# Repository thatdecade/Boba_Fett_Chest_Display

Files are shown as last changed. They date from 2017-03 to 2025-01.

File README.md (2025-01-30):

# Boba-Fett-Chest-Display
This is the software and hardware design for the display on Boba Fett’s chest plate.  It was developed in collaboration with Joshua Kane.

The animation script is laid out in an easy to understand format.  Each segment of the display is fully programmable in the animation.
Just 12 lines of code to processes the animation and update the display!

Video Demo: https://www.flickr.com/photos/dwest2/23788341410

Video Build Guide: https://youtu.be/qv9qykpNFjM

Part List: https://www.mouser.com/ProjectManager/ProjectDetail.aspx?AccessID=554d07ab05

PCB Main Board: https://oshpark.com/shared_projects/f60TBgnX

PCB Bargraph Board: https://www.oshpark.com/shared_projects/E4qjCF4r

PCB Assembly Guide: http://www.westaby.net/2016/01/guide-boba-fett-chest-display/

Animation sequences for ESB, RTOJ, and Mandalorian are included.  For a customized sequence:
- Open the sequence_builder.xlsx or visit: https://www.westaby.net/7seg/
- There are three tabs, Seq Builder, Encoder, and Decoder.
- On the Seq Builder tab, enter 1s and 0s to light up the characters as you wish.
- Copy the indicated cell and paste the values to the sequence rows (right click, paste values)
- When finished, copy the finished sequence into the arduino code.
- Update CHAR_SEQUENCE_SIZE with the number of lines in your animation sequence
------------------------
# Boba-Fett-Chest-Display

This is the software and hardware design for the display on Boba Fett’s chest plate. It was developed in collaboration with Joshua Kane.

The animation script is laid out in an easy to understand format.  Each segment of the display is fully programmable in the animation.
Just 12 lines of code to processes the animation and update the display!

## Video Resources
- **Video Demo**: [Watch on Flickr](https://www.flickr.com/photos/dwest2/23788341410)
- **Video Build Guide**: [Watch on YouTube](https://youtu.be/qv9qykpNFjM)

## Hardware Resources
- **Part List**: [View on Mouser](https://www.mouser.com/ProjectManager/ProjectDetail.aspx?AccessID=554d07ab05)
- **PCB Main Board**: [View on OshPark](https://oshpark.com/shared_projects/f60TBgnX)
- **PCB Bargraph Board**: [View on OshPark](https://www.oshpark.com/shared_projects/E4qjCF4r)
- **PCB Assembly Guide**: [Read the Guide](http://www.westaby.net/2016/01/guide-boba-fett-chest-display/)

## Animation Sequences
Animation sequences for **ESB**, **ROTJ**, and **Mandalorian** are included. To create a customized sequence, follow these steps using the [7-Segment LED Display Animator Tool](https://www.westaby.net/7seg/):

1. **Open the Animator Tool**: [https://www.westaby.net/7seg/](https://www.westaby.net/7seg/) 

2. **Create Your Animation**:
   - Click on the segments of each digit to turn them on or off, creating your desired pattern.
   - Click the **"Save Frame"** button to record the current state of the display, adding it as a frame in your animation sequence.
   - Click the **"Playback Animation"** button to preview your animation on the display.
   - Once satisfied with your animation, click the **"Copy Code"** button to copy the animation data to your clipboard. This can be directly pasted into your Arduino code.

3. **Configure Arduino Code**:
   - In your Arduino sketch, paste the copied animation data where appropriate.
   - Update the `CHAR_SEQUENCE_SIZE` constant to match the number of frames in your animation sequence.

## Getting Started
1. **Assemble the Hardware**:
   - Follow the [PCB Assembly Guide](http://www.westaby.net/2016/01/guide-boba-fett-chest-display/) to assemble the main and bargraph PCBs.
   - Ensure all components are correctly placed and soldered.

2. **Upload the Firmware**:
   - Connect your assembled display to your computer via USB.
   - Open the Arduino IDE and load your sketch.  
   - Paste the animation data into your sketch and upload it to the microcontroller.

3. **Power Up**:
   - Once the firmware is uploaded, power the display to see your custom animations in action.

## License
[GNU General Public License v3.0](LICENSE)

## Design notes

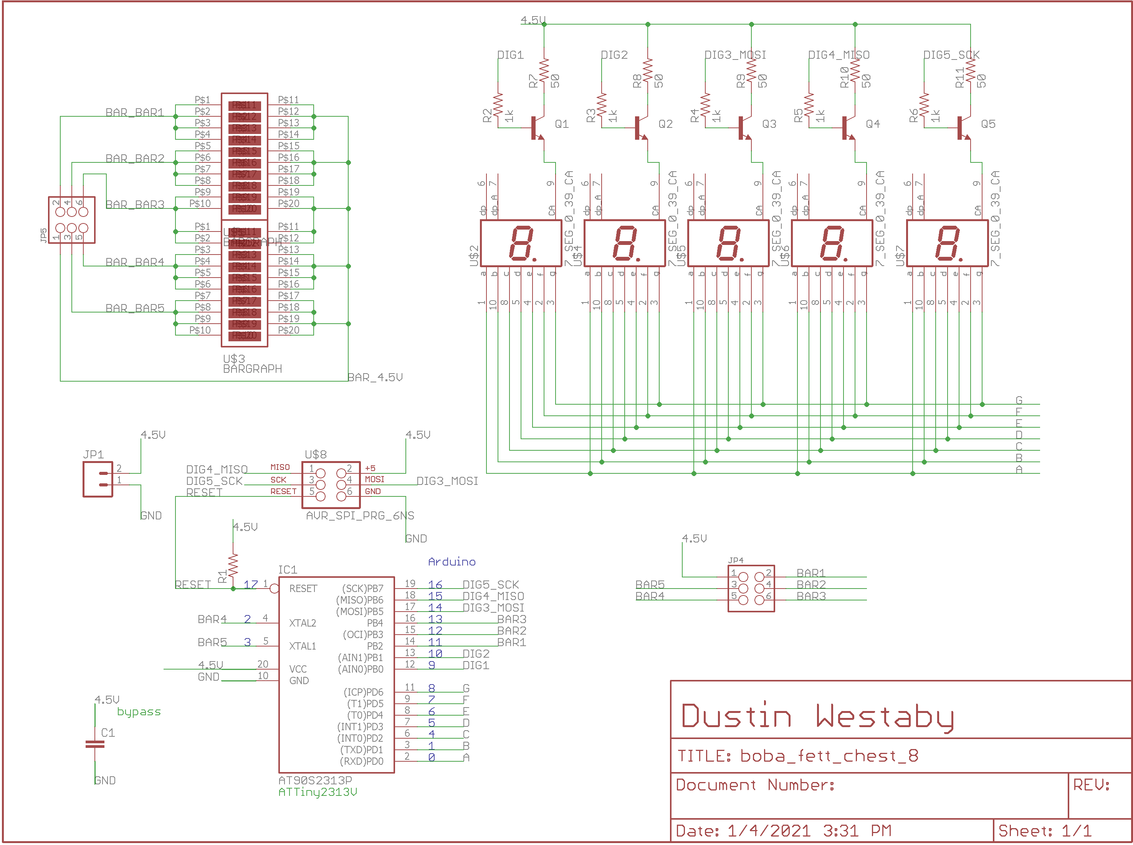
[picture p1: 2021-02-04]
PCB/schematic.png

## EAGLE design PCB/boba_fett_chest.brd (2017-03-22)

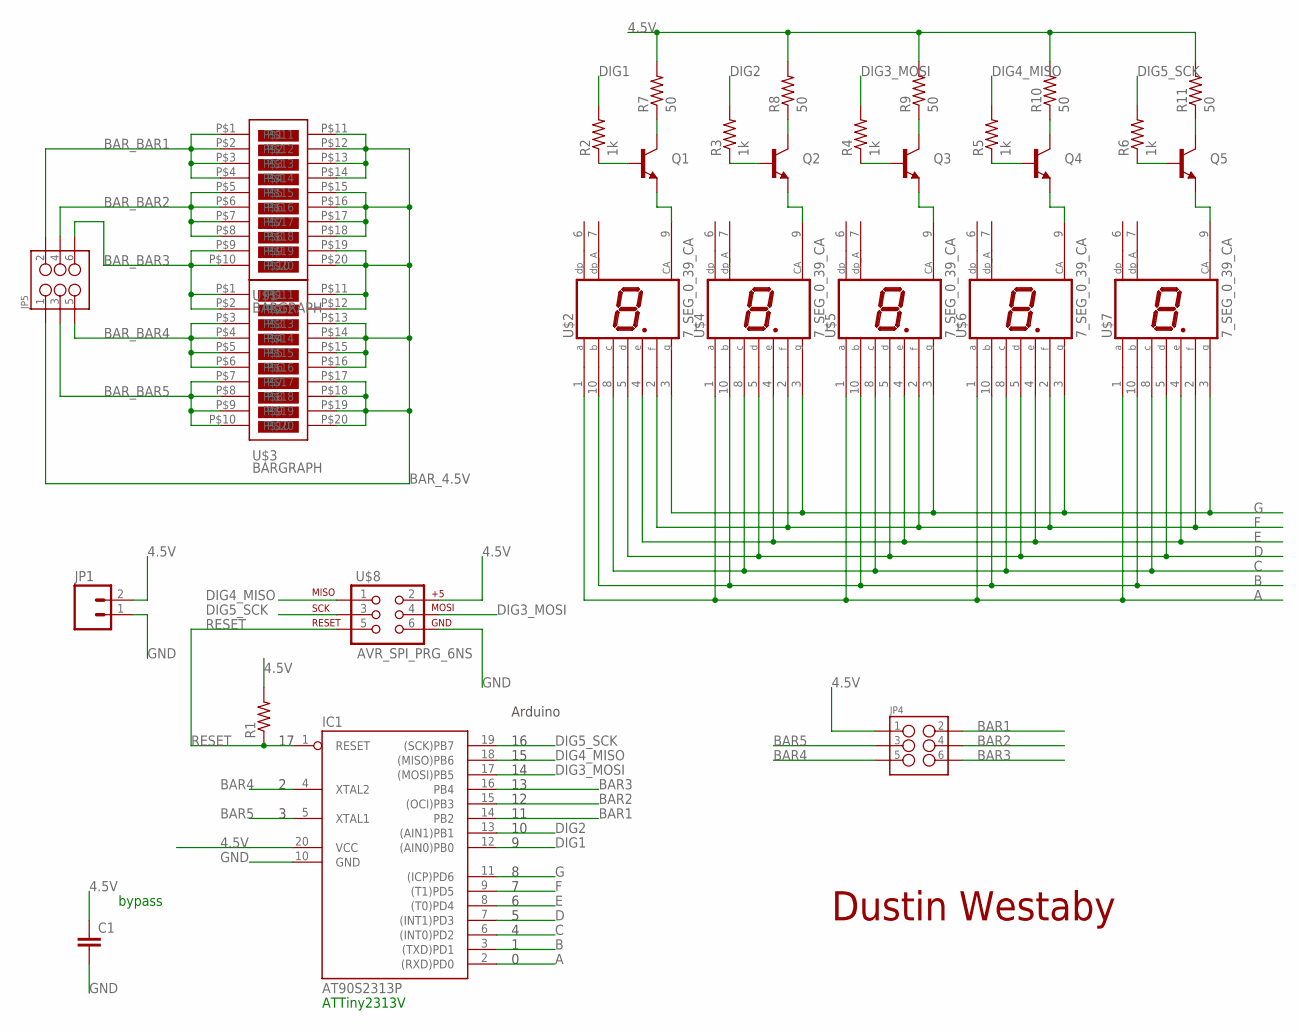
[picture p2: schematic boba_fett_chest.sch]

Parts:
C1: CAPCAP-PTH-2MM; CAP-PTH-2MM
IC1: AT90S2313P; DIL20
JP1: M02PTH; 1X02
JP4, JP5: M03X22X3_SILK_SM; 2X3
Q1, Q2, Q3, Q4, Q5: TRANSISTOR_NPNTO92; TO-92
R1: RESISTORPTH1; AXIAL-0.3
R2, R3, R4, R5, R6: 1k; AXIAL-0.3
R7, R8, R9, R10, R11: 50; AXIAL-0.3
U$1, U$3: BARGRAPH
U$2, U$4, U$5, U$6, U$7: 7_SEG_0_39_CA; 0_39_DISP
U$8: AVR_SPI_PRG_6NS; 2X3-NS

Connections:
4.5V: C1.1, IC1.20 (VCC), JP1.2, JP4.1, R1.P$2 (2), R7.P$2 (2), R8.P$2 (2), R9.P$2 (2), R10.P$2 (2), R11.P$2 (2), U$8.2
A: IC1.2 ((RXD)PD0), U$2.1 (A), U$4.1 (A), U$5.1 (A), U$6.1 (A), U$7.1 (A)
B: IC1.3 ((TXD)PD1), U$2.10 (B), U$4.10 (B), U$5.10 (B), U$6.10 (B), U$7.10 (B)
BAR1: IC1.14 (PB2), JP4.2
BAR2: IC1.15 ((OCI)PB3), JP4.4
BAR3: IC1.16 (PB4), JP4.6
BAR4: IC1.4 (XTAL2), JP4.5
BAR5: IC1.5 (XTAL1), JP4.3
BAR_4.5V: JP5.1, U$1.P$11, U$1.P$12, U$1.P$13, U$1.P$14, U$1.P$15, U$1.P$16, U$1.P$17, U$1.P$18, U$1.P$19, U$1.P$20, U$3.P$11, U$3.P$12, U$3.P$13, U$3.P$14, U$3.P$15, U$3.P$16, U$3.P$17, U$3.P$18, U$3.P$19, U$3.P$20
BAR_BAR1: JP5.2, U$1.P$1, U$1.P$2, U$1.P$3, U$1.P$4
BAR_BAR2: JP5.4, U$1.P$5, U$1.P$6, U$1.P$7, U$1.P$8
BAR_BAR3: JP5.6, U$1.P$9, U$1.P$10, U$3.P$1, U$3.P$2
BAR_BAR4: JP5.5, U$3.P$3, U$3.P$4, U$3.P$5, U$3.P$6
BAR_BAR5: JP5.3, U$3.P$7, U$3.P$8, U$3.P$9, U$3.P$10
C: IC1.6 ((INT0)PD2), U$2.8 (C), U$4.8 (C), U$5.8 (C), U$6.8 (C), U$7.8 (C)
D: IC1.7 ((INT1)PD3), U$2.5 (D), U$4.5 (D), U$5.5 (D), U$6.5 (D), U$7.5 (D)
DIG1: IC1.12 ((AIN0)PB0), R2.P$2 (2)
DIG2: IC1.13 ((AIN1)PB1), R3.P$2 (2)
DIG3_MOSI: IC1.17 ((MOSI)PB5), R4.P$2 (2), U$8.4
DIG4_MISO: IC1.18 ((MISO)PB6), R5.P$2 (2), U$8.1
DIG5_SCK: IC1.19 ((SCK)PB7), R6.P$2 (2), U$8.3
E: IC1.8 ((T0)PD4), U$2.4 (E), U$4.4 (E), U$5.4 (E), U$6.4 (E), U$7.4 (E)
F: IC1.9 ((T1)PD5), U$2.2 (F), U$4.2 (F), U$5.2 (F), U$6.2 (F), U$7.2 (F)
G: IC1.11 ((ICP)PD6), U$2.3 (G), U$4.3 (G), U$5.3 (G), U$6.3 (G), U$7.3 (G)
GND: C1.2, IC1.10 (GND), JP1.1, U$8.6
unnamed: Q5.1 (E), U$7.9 (CA)
unnamed: Q4.1 (E), U$6.9 (CA)
unnamed: Q3.1 (E), U$5.9 (CA)
unnamed: Q2.1 (E), U$4.9 (CA)
unnamed: Q1.1 (E), U$2.9 (CA)
unnamed: Q1.2 (B), R2.P$1 (1)
unnamed: Q2.2 (B), R3.P$1 (1)
unnamed: Q3.2 (B), R4.P$1 (1)
unnamed: Q4.2 (B), R5.P$1 (1)
unnamed: Q5.2 (B), R6.P$1 (1)
unnamed: Q1.3 (C), R7.P$1 (1)
unnamed: Q2.3 (C), R8.P$1 (1)
unnamed: Q3.3 (C), R9.P$1 (1)
unnamed: Q4.3 (C), R10.P$1 (1)
unnamed: Q5.3 (C), R11.P$1 (1)
RESET: IC1.1 (RESET), R1.P$1 (1), U$8.5

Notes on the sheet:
bypass
ATTiny2313V
Arduino
Dustin Westaby

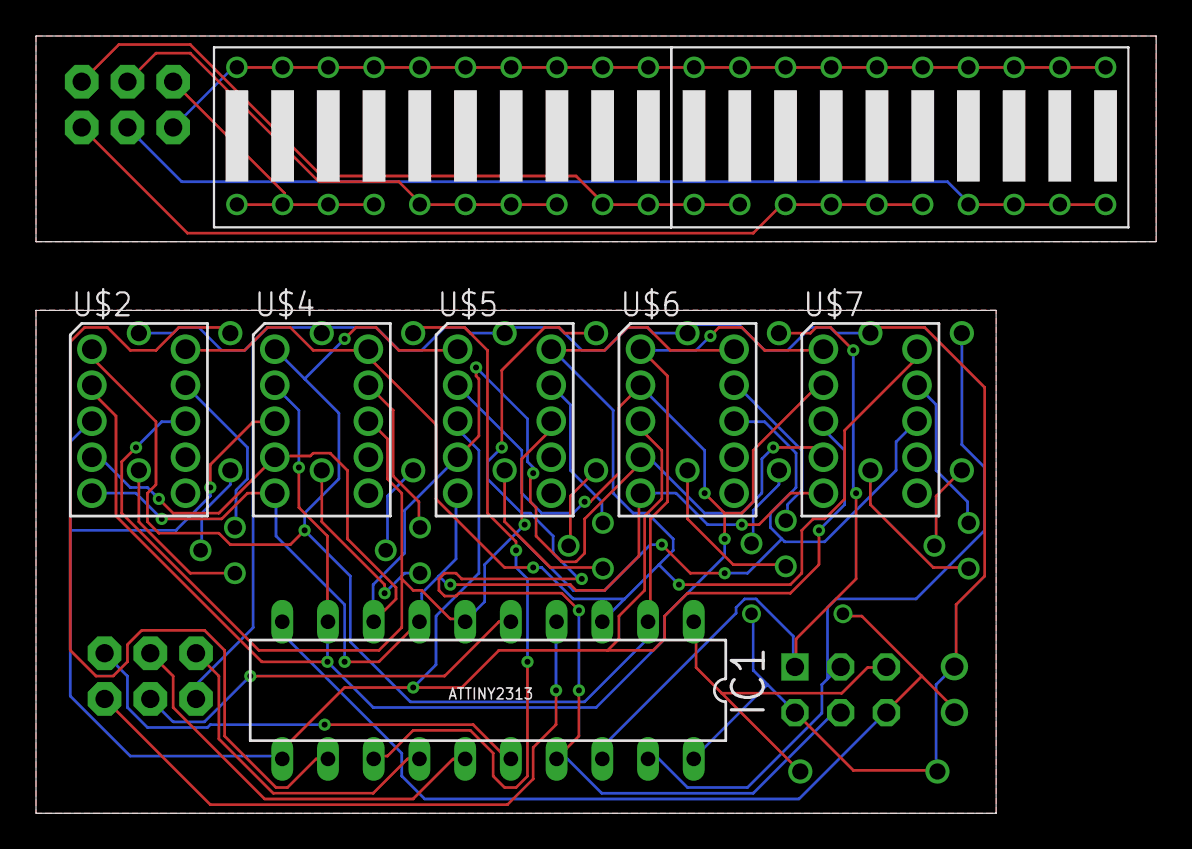
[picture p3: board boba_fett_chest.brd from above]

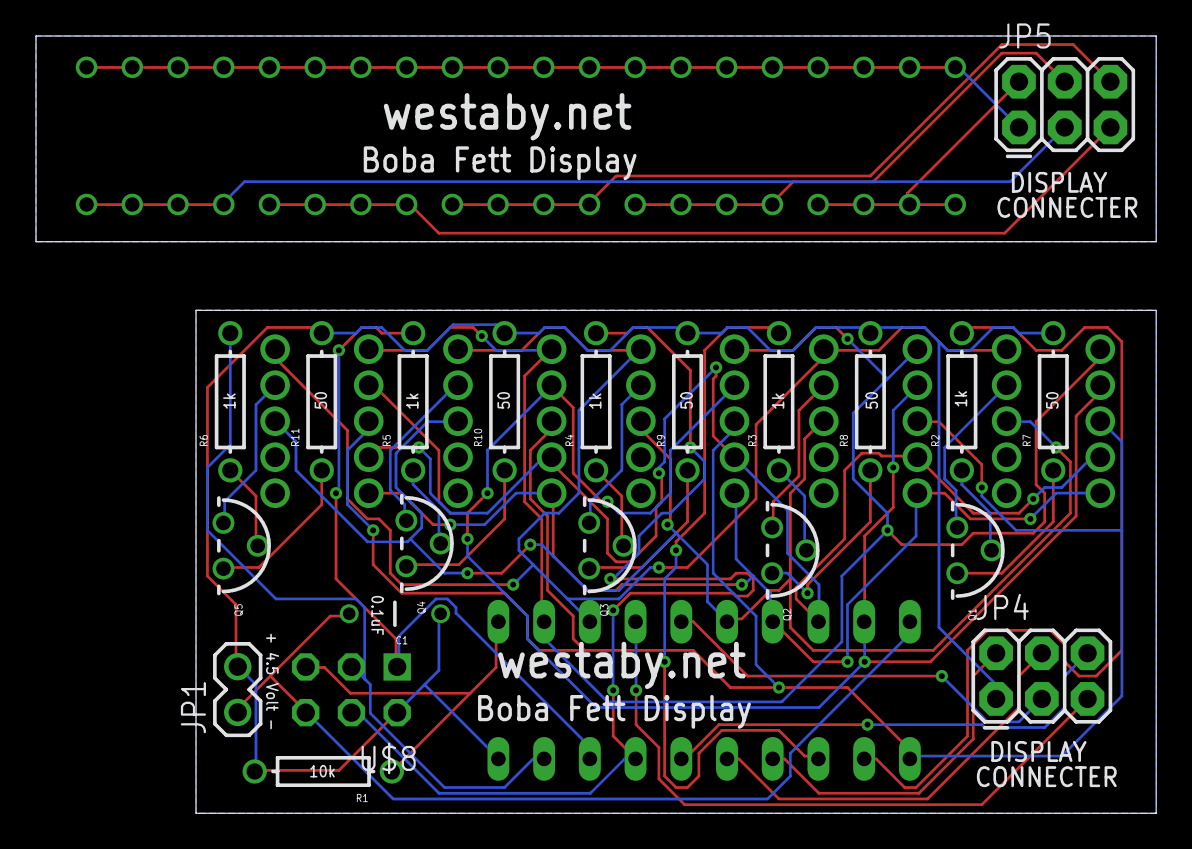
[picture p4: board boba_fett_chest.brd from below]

Board: 2 copper layers, 53.3 x 27.9 mm, 29 parts (21 on the bottom side), 41 nets.

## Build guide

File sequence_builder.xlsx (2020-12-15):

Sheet: Seq Builder
Tab copied from Encoder
Switch |  | 0 |  |  | 0 |  |  | 1 |  |  | 0 |  |  | 1
These | 0 |  | 1 | 0 |  | 1 | 1 |  | 0 | 1 |  | 0 | 0 |  | 1
 |  | 0 |  |  | 0 |  |  | 0 |  |  | 1 |  |  | 0
 | 1 |  | 0 | 0 |  | 1 | 1 |  | 1 | 0 |  | 0 | 1 |  | 1
 |  | 1 |  |  | 0 |  |  | 1 |  |  | 0 |  |  | 1
 | 0b10011010 |  |  | 0b10000110 |  |  | 0b10111101 |  |  | 0b11100000 |  |  | 0b10011111
Copy This | {0b10011010, 0b10000110, 0b10111101, 0b11100000, 0b10011111, 0xFF},
 | Paste each step of sequence below
1 | {0b11111111, 0b11111111, 0b11111111, 0b11111111, 0b11111111, 0xFF},
2 | {0b10001001, 0b11000010, 0b10100100, 0b10000000, 0b11001110, 0xFF}, //HG28
3 | {0b10000000, 0b10000000, 0b10000000, 0b10000000, 0b10000000, 0xFF}, //88888
4 | {0b10111101, 0b11011011, 0b11110110, 0b11001111, 0b10111110, 0xFF}, // -'',_|-
5 | {0b10100001, 0b11000001, 0b10000110, 0b10001100, 0b11111101, 0x01}, //dUEP'
6 | {0b10001001, 0b10010011, 0b10100100, 0b10011000, 0b11001111, 0xFF}, //H5291
7 | {0b10001010, 0b10000110, 0b10101000, 0b11100000, 0b10001111, 0xFF}, //hEaJt
8 | {0b10000110, 0b10000110, 0b10101100, 0b11110000, 0b10011111, 0xFF}, //EE2Cl
9 | {0b10111001, 0b11010111, 0b11111110, 0b11001111, 0b10111110, 0xFF}, //t,-|_
10 | {0b10011010, 0b10000110, 0b10111101, 0b11100000, 0b10011111, 0xFF}, //5E-J-

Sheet: Encoder
Switch |  | 1 |  |  | 1 |  |  | 1 |  |  | 1 |  |  | 1
These | 1 |  | 1 | 1 |  | 1 | 1 |  | 1 | 1 |  | 1 | 1 |  | 1
 |  | 1 |  |  | 1 |  |  | 1 |  |  | 1 |  |  | 1
 | 1 |  | 1 | 1 |  | 1 | 1 |  | 1 | 1 |  | 1 | 1 |  | 1
 |  | 1 |  |  | 1 |  |  | 1 |  |  | 1 |  |  | 1
 | 0b11111111 |  |  | 0b11111111 |  |  | 0b11111111 |  |  | 0b11111111 |  |  | 0b11111111
Copy This | {0b11111111, 0b11111111, 0b11111111, 0b11111111, 0b11111111, 0xFF},
 | Paste each step of sequence below
1
2
3
4
5
6
7
8
9
10
11
12
13
14

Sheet: Decoder
Paste Here | {0b10011010, 0b10000110, 0b10111101, 0b11100000, 0b10011111, 0xFF},
Decoded
Dig/Segs | 10011010 |  |  |  | 10000110 |  |  |  | 10111101 |  |  |  | 11100000 |  |  |  | 10011111
0 |  | 0 |  | 0 |  | 0 |  | 0 |  | 1 |  | 1 |  | 0 |  | 0 |  | 1
0 | 0 |  | 1 | 0 | 0 |  | 1 | 1 | 1 |  | 0 | 1 | 1 |  | 0 | 0 | 0 |  | 1
1 |  | 0 |  | 0 |  | 0 |  | 1 |  | 0 |  | 0 |  | 1 |  | 1 |  | 0
1 | 1 |  | 0 | 0 | 0 |  | 1 | 1 | 1 |  | 1 | 0 | 0 |  | 0 | 1 | 1 |  | 1
0 |  | 1 |  | 1 |  | 0 |  | 1 |  | 1 |  | 0 |  | 0 |  | 1 |  | 1
1 |  |  |  | 1 |  |  |  | 0 |  |  |  | 0 |  |  |  | 1
0 |  |  |  | 0 |  |  |  | 1 |  |  |  | 0 |  |  |  | 1

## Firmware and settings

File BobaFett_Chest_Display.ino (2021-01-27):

/*
  Boba Fett Chest Display Circuit
  This is the software for the display on Boba Fett’s chest plate.
  Arduino IDE.

  Last Modified: Jan 27, 2021

  Authors: Joshua Kane, Dustin Westaby

  Video Demos:
  https://www.flickr.com/photos/dwest2/23788341410
  https://youtu.be/mR4YBt7tsDA

  Part List:
  http://www.mouser.com/ProjectManager/ProjectDetail.aspx?AccessID=7c6a316116

  PCB Main Board:
  https://www.oshpark.com/shared_projects/ml5VjhuM

  PCB Bargraph Board:
  https://www.oshpark.com/shared_projects/E4qjCF4r

  Usage: 
   - Some example sequences are given below. Comment / Uncomment the options you want to use.
   - For a customized sequence, use the sequence_builder.xlsx
*/

 /* =========================
      Options
   ========================= */

//#define USE_MANDO_ANIMATION
#define USE_ESB_ANIMATION
//#define USE_ROTJ_ANIMATION

#define USING_COMMON_ANODE_7SEG_DISPLAYS
//#define USING_COMMON_CATHODE_7SEG_DISPLAYS //Note: Common cathode also needs special wiring, email thatdecade@gmail.com

 /* =========================
      Animations
   ========================= */

 /* =========================
      Structure Constants
   ========================= */

#ifdef USE_MANDO_ANIMATION
// START: Mandalorian Animation

#define ASYNC_BARGRAPH

//lower = faster
//higher = slower
#define BASE_SPEED 3
#define BAR_SPEED 15 //at base = 3, allowed values: 5, 10, 15, 16, 33

#define BAR_SEQ_SIZE 8
#define CHAR_SEQUENCE_SIZE 10

const byte char_sequence[10][5] =
{
    //  DIGIT 1     DIGIT 2     DIGIT 3     DIGIT 4     DIGIT 5  
    //  GFEDCBA     GFEDCBA     GFEDCBA     GFEDCBA     GFEDCBA         
    {0b11111111, 0b11111111, 0b11111111, 0b11111111, 0b11111111},            // 0
    {0b10001001, 0b11000010, 0b10100100, 0b10000000, 0b11001110}, //HG28|    // 1
    {0b10000000, 0b10000000, 0b10000000, 0b10000000, 0b10000000}, //88888    // 2
    {0b10111101, 0b11011011, 0b11110110, 0b11001111, 0b10111110}, // -'',_|- // 3
    {0b10100001, 0b11000001, 0b10000110, 0b10001100, 0b11111101},  //dUEP'   // 4
    {0b10001001, 0b10010011, 0b10100100, 0b10011000, 0b11001111}, //H5291    // 5
    {0b10001010, 0b10000110, 0b10101000, 0b11100000, 0b10001111}, //hEaJt    // 6
    {0b10000110, 0b10000110, 0b10101100, 0b11110000, 0b10011111}, //EE2Cl    // 7
    {0b10111001, 0b11010111, 0b11111110, 0b11001111, 0b10111110}, //t,-|_    // 8
    {0b10011010, 0b10000110, 0b10111101, 0b11100000, 0b10011111}, //5E-J-    // 9
};

const byte bar_sequence[8] =
{           //  BARGRAPH
            //   12345
    0x00, //  0 |    =|
    0x01, //  1 |   = |
    0x02, //  2 |  =  |
    0x03, //  3 | =   |
    0x04, //  4 |=    |
    0x03, //  5 | =   |
    0x02, //  6 |  =  |
    0x01, //  7 |   = |
};

// END: Mandalorian Animation
#endif

// START: ESB Animation
#ifdef USE_ESB_ANIMATION

#define SYNC_BARGRAPH

//lower = faster
//higher = slower
#define BASE_SPEED 3

#define CHAR_SEQUENCE_SIZE 11

const byte char_sequence[CHAR_SEQUENCE_SIZE][5] =
{
    //  DIGIT 1     DIGIT 2     DIGIT 3     DIGIT 4     DIGIT 5  
    //  GFEDCBA     GFEDCBA     GFEDCBA     GFEDCBA     GFEDCBA         
    {0b11111111, 0b11111111, 0b11111111, 0b11111111, 0b11111111},  //      // 0
    {0b10100001, 0b11000001, 0b10000110, 0b10001100, 0b11111101},  //dUEP' // 1
    {0b10000000, 0b10000000, 0b10000000, 0b10000000, 0b10000000},  //88888 // 2
    {0b10100001, 0b11000001, 0b10000110, 0b10001100, 0b11111101},  //dUEP' // 3
    {0b10001011, 0b10000110, 0b10001000, 0b10100001, 0b10001001},  //hEADH // 4
    {0b10111101, 0b11011011, 0b11110110, 0b11001111, 0b10111110},  //'.=¦= // 5
    {0b10100001, 0b11000001, 0b10000110, 0b10001100, 0b11111101},  //dUEP' // 6
    {0b10001001, 0b10010010, 0b10100100, 0b10011000, 0b11111001},  //H5291 // 7
    {0b10111101, 0b11011011, 0b11110110, 0b11001111, 0b10111110},  //'.=¦= // 8
    {0b10100001, 0b11000001, 0b10000110, 0b10001100, 0b11111101},  //dUEP' // 9
    {0b10001001, 0b11000010, 0b10100100, 0b10000000, 0b11001110},  //H{E8¬ // 10
};

const byte bar_sequence[CHAR_SEQUENCE_SIZE] =
{           //  BARGRAPH
            //   12345
    0xFF, //  0 |     |
    0x01, //  1 | =   |
    0x03, //  2 |   = |
    0x02, //  3 |  =  |
    0x04, //  4 |    =|
    0xFF, //  5 |     |
    0x01, //  6 | =   |
    0x00, //  7 |=    |
    0xFF, //  8 |     |
    0x01, //  9 | =   |
    0xFF, // 10 |     |
};

// END: ESB Animation
#endif

#ifdef USE_ROTJ_ANIMATION
// START: ROTJ Animation

#define SYNC_BARGRAPH

//lower = faster
//higher = slower
#define BASE_SPEED 3

#define CHAR_SEQUENCE_SIZE 8

const byte char_sequence[CHAR_SEQUENCE_SIZE][5] =
{
    //  DIGIT 1     DIGIT 2     DIGIT 3     DIGIT 4     DIGIT 5  
    //  GFEDCBA     GFEDCBA     GFEDCBA     GFEDCBA     GFEDCBA         
    {0b10000000, 0b10000000, 0b10000000, 0b10000000, 0b10000000},  //88888 // 0
    {0b10111101, 0b11011011, 0b11110110, 0b11001111, 0b10111110},  //'.=¦= // 1
    {0b10100001, 0b11000001, 0b10000110, 0b10001100, 0b11111101},  //dUEP' // 2
    {0b10001001, 0b11000010, 0b10100100, 0b10000000, 0b11001110},  //HG28r // 3
    {0b10001001, 0b10010010, 0b10100100, 0b10011000, 0b11111001},  //H5291 // 4
    {0b10111101, 0b11011011, 0b11110110, 0b11001111, 0b10111110},  //'.=¦= // 5
    {0b10001011, 0b10000110, 0b10001000, 0b10100001, 0b10001001},  //hEADH // 6
    {0b10001001, 0b11000010, 0b10100100, 0b10000000, 0b11001110},  //HG28r // 7
};

const byte bar_sequence[CHAR_SEQUENCE_SIZE] =
{           //  BARGRAPH
            //   12345
    0x03, //  0 |   = |
    0xFF, //  1 |     |
    0x02, //  2 |  =  |
    0xFF, //  3 |     |
    0x00, //  4 |=    |
    0xFF, //  5 |     |
    0x04, //  6 |    =|
    0xFF, //  7 |     |
};

// END: ROTJ Animation
#endif


/* *************************************************** */
/* DO NOT EDIT BELOW THIS LINE */
/* *************************************************** */

// This section contains board specific information

//approx 2400 for 2 seconds of delay, must be divisible by the BAR_SEQ_SIZE * BAR_ANIMATION_SPEED_DIVIDER
#define NUM_LOOPS_PER_WORD (BASE_SPEED*100*8)

#ifdef ASYNC_BARGRAPH
#define BAR_ANIMATION_SPEED_DIVIDER  (BAR_SPEED*10)
#endif

#define NUM_BARS       5
#define NUM_DIGITS     5
#define NUM_SEGMENTS   7

#if defined(USING_COMMON_ANODE_7SEG_DISPLAYS)

#define BAR_ON      LOW
#define BAR_OFF     HIGH
#define CHAR_ON      HIGH
#define CHAR_OFF     LOW

#else //USING_COMMON_CATHODE_7SEG_DISPLAYS

#define BAR_ON      HIGH
#define BAR_OFF     LOW
#define CHAR_ON      LOW
#define CHAR_OFF     HIGH

#endif

const byte pinmap_bars[NUM_BARS] =
{
	11,   // Bar 1
	12,   // Bar 2
	13,   // Bar 3
	2,    // Bar 4
	3,    // Bar 5
};

const byte pinmap_segments[NUM_SEGMENTS] =
{
	0,   // Segment A
	1,   // Segment B
	4,   // Segment C
	5,   // Segment D
	6,   // Segment E
	7,   // Segment F
	8,   // Segment G
};

const byte pinmap_digits[NUM_DIGITS] =
{
	9,    // Digit 1
	10,   // Digit 2
	14,   // Digit 3
	15,   // Digit 4
	16,   // Digit 5
};

/* *************************************************** */
/* CODE */
/* *************************************************** */

// the setup routine runs once when you press reset:
void setup()
{
  // Setup external pins for the BARs across the top
  for (int i = 0; i < 5; i++)
  {
    pinMode( pinmap_bars[i], OUTPUT);
    digitalWrite(pinmap_bars[i], HIGH);
  }

  // Setup external pins for the segemnt data
  for (int i = 0; i < 7; i++)
  {
    pinMode( pinmap_segments[i], OUTPUT);
    digitalWrite(pinmap_segments[i], HIGH);
  }

  // Setup external pins for the segment selector
  for (int i = 0; i < 5; i++)
  {
    pinMode( pinmap_digits[i], OUTPUT);
    digitalWrite(pinmap_digits[i], LOW);
  }
}



// Walks through the entire sentence, word by word, repeating each word
//   multiple times so that they mind perceives a roughly two second delay
//   between each new word before the loop starts again.
void loop()
{
  // Move through the words in the sentence one at a time
  for ( int idxWord = 0; idxWord < CHAR_SEQUENCE_SIZE; idxWord++)
  {
    // Repeat each word until we've hit roughly 2 seconds per word
    for ( int idxDelay = 0; idxDelay < NUM_LOOPS_PER_WORD; idxDelay++)
    {
      word_test( idxWord ) ;
#ifdef ASYNC_BARGRAPH
      bar_test ( (idxDelay/BAR_ANIMATION_SPEED_DIVIDER) % BAR_SEQ_SIZE );
#endif
    }
#ifdef SYNC_BARGRAPH
    bar_test ( idxWord );
#endif

  }
}

// Walks through each character in the specified word index, delaying
//   only 1/10th of a second between characters as to allow the mind
//   to see the letter even though it's on only 1/5 of the time.
void word_test(int idxWord )
{
  // Now, let's work on the word we would like to display
  for( int character = 0 ; character < NUM_DIGITS; character++ )
  {
    int charValue = char_sequence[idxWord][character] ;

    // Setup the character on the data lines first
    for( int segment = 0 ; segment < NUM_SEGMENTS; segment++ )
      digitalWrite( pinmap_segments[segment], ( charValue >> segment ) & 1 ) ;

    // Blink Character
    digitalWrite( pinmap_digits[character],CHAR_ON);
    delay(0);
    digitalWrite( pinmap_digits[character],CHAR_OFF);
  }

}

void bar_test(int index)
{
  static int old_index = 0;
  if(index != old_index)
  {
    digitalWrite( pinmap_bars[bar_sequence[old_index]], BAR_OFF);
    digitalWrite( pinmap_bars[bar_sequence[index]],     BAR_ON);
    old_index = index;
  }
}

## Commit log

2020-12-15 Sequence builder excel file
    Prepping for a mandalorian style animation
    [sequence_builder.xlsx]
2021-01-03 Mandalorian sequence added.
    Reworked animation routines to allow the bargraph to be run async from the character animation.
    [BobaFett_Chest_Display.ino]
2021-01-03 Added mandalorian animation.
    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
    [BobaFett_Chest_Display.ino]

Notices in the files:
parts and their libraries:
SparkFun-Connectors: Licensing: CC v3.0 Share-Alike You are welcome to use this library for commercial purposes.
